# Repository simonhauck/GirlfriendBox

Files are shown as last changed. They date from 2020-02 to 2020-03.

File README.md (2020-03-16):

# GirlfriendBox_Present
This is a self-made present for your girlfriend or wife.

<p align="center">
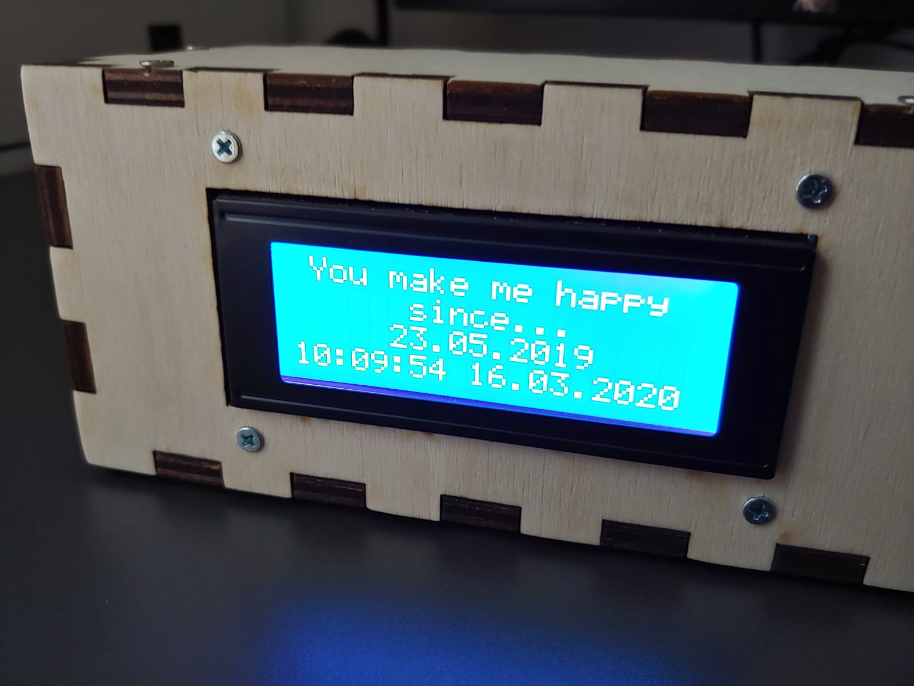
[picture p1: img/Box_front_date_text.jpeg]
  
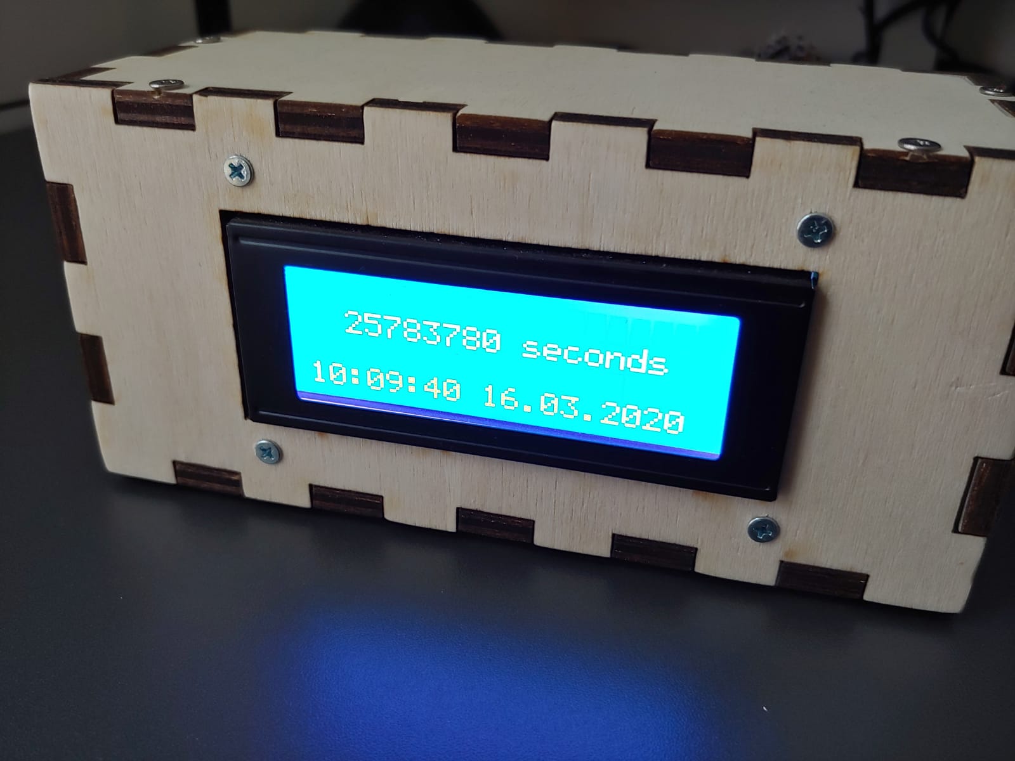
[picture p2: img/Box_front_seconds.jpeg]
  
</p>

It is a box, that counts how long you have been together or married in different units. It cycles through seconds, minutes, hours, days, months, years as well as a customizable text, that shows your “Date”. Additionally, it also displays the current date & time at the bottom of the display. 

The project idea is inspired by this [video](https://www.youtube.com/watch?v=PbRNsSK7r4M), but the code as well as the box were created by myself.

## What you need
- 1 Arduino, which is the "brain". I used the [Arduino Nano V3](https://store.arduino.cc/arduino-nano)
- 1 Real-Time-Clock Module, which keeps track of the time. I used the [DS3231](https://create.arduino.cc/projecthub/MisterBotBreak/how-to-use-a-real-time-clock-module-ds3231-bc90fe)
- 1 [I2C-LCD-Display](https://www.amazon.de/SainSmart-Character-Display-Mega2560-Duemilanove/dp/B007XRHBKA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) with 20 * 4 characters
- 3 [Buttons](https://www.amazon.de/Youmile-100er-Pack-Miniatur-Mikro-Taster-Tastschalter-Qualit%C3%A4tsschalter-Miniature-6-x-5-mm/dp/B07Q1BXV7T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) to set the current time
- 2 [Switches](https://www.digikey.de/product-detail/de/e-switch/EG1201A/EG1902-ND/101723?productid=101723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). The first is for power and the second for the backlicht of the display
- Optionally
  - 1 [Lipo-Battery](https://www.amazon.de/gp/product/B07XCRTXL9/ref=ppx_yo_dt_b_asin_title_o00_s00?ie=UTF8&psc=1), so that you don't require always a power cable. I used a model with 3.7V and 2600mAh
  - 1 [Lipo-Charging-Circuit](https://www.amazon.de/IZOKEE-TP4056-Lademodul-Lithium-Batterie-Charger/dp/B077XW1XBJ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), so that you can charge the battery 
  - 1 [Boost-Converter](https://www.amazon.de/gp/product/B07KW61VYM/ref=ppx_yo_dt_b_asin_title_o00_s00?ie=UTF8&psc=1), which increases the battery voltage to 7 Volts
  - Some soldering gear, if you want to make a nice PCB

## Build the circuit
<p align="center">
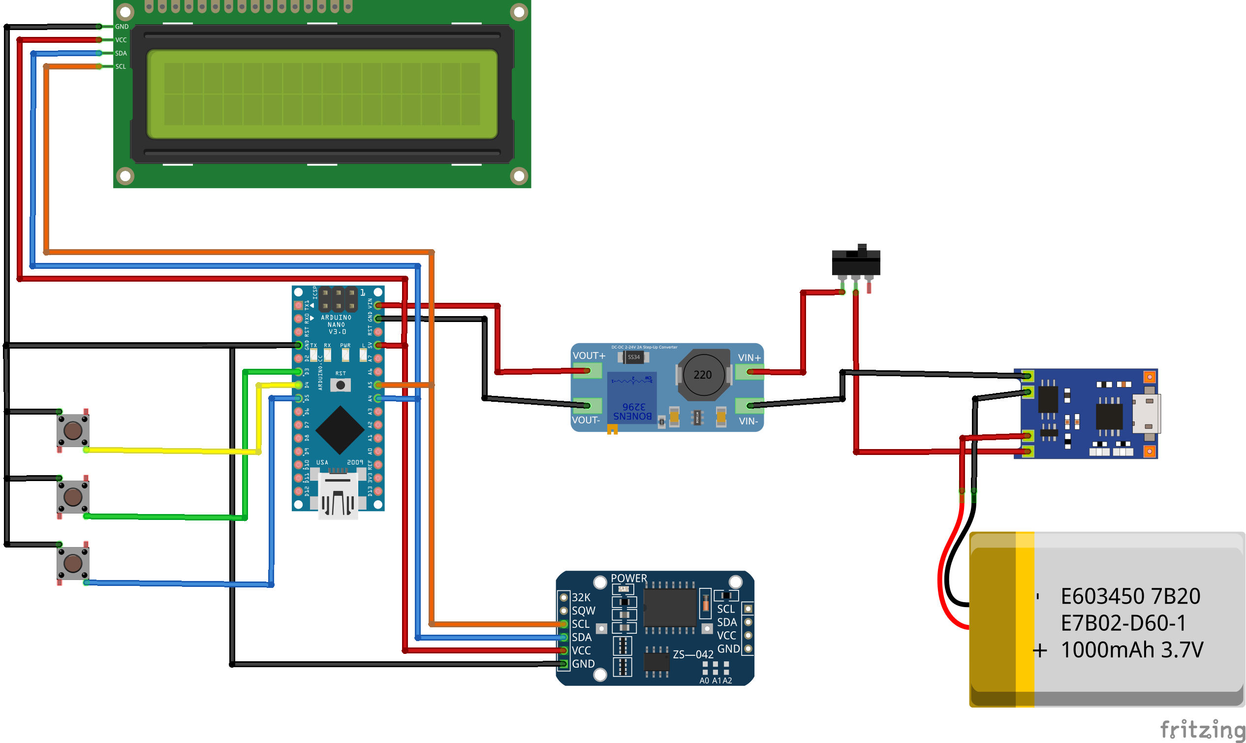
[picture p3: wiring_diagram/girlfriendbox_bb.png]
  
</p>
To build the circuit gather all the components and create the wiring according to the scheme provided in the “wiring_diagram” folder. Configure the boost-converter to output 7V. You can do this with a multimeter. Connect the probes to the + Pin  and - Pin of the boost-converter and measure the voltage. Rotate the potentiometer on the boost-convert until the multimeter shows 7V.

Note that this diagram contains only one switch for the power. The second is connected to the backlight pins of the I2C-Display. And now you are already done with the circuit :D yeahh 

Optionally you can create a small PCB for the wiring. This makes the assembly much cleaner. Additionally, I recommend using plugs between the components. This makes the assembly and/or maintenance if something breaks much more easy.

## Upload the code
After creating the circuit open the “girlfriendbox.ino” file with the Arduino IDE or something similar. Add the required libraries from the “lib” folder. In the Arduino IDE you can do this by clicking Sketch > Include Library > Add .ZIP Library. 
Now you should be able to upload the code to the Arduino and the program should run.

```C++
#define START_TIME_OF_COUNTER_TEXT "23.05.2019"
#define START_TIME_OF_COUNTER_UNIX_TIMESTAMP 1558569600
#define START_TIME_YEAR 2019
#define START_TIME_MONTH 5
#define START_TIME_DAY 23
```
The first one is the date shown on the display, the second is the same date as unix-timestamp, which is used to calculate the passed seconds, minutes, hours and days. You can use any online converter to get this timestamp. Note: You should add an offset for your timezone. So if you are in timezone +1 and your date is “23.05.2019 00:00” calculate the timestamp with “23.05.2019 01:00”. Last, add the date values for the day, month and year field. Personally I would prefer to calculate these values, but this would be a really big pain and soooo I ignored it... Anyways these are used to calculate the passed months and years, and of course, they only change on the monthly and yearly anniversary. 

Now you can change some more minor details, like the welcome text which will be shown initally and the units for seconds, month, ... , year if you prefer a different language. 

Upload the code to the arduino and set the current date and time. You can do this by pressing the config button (Pin 3). Increase and decrease the values with the buttons on Pin 4 and 5. If the value ist correct press the config button again.

## Build the case
Of course, you need a case for your box. I created one out of 6mm wood with the help of a laser cutter. If you have access to one of these, you can use the .dxf file in the folder “lasercutter_files”. If not, you have to manually cut/saw a box or you search for a company that will do this for you.

<p align="center">
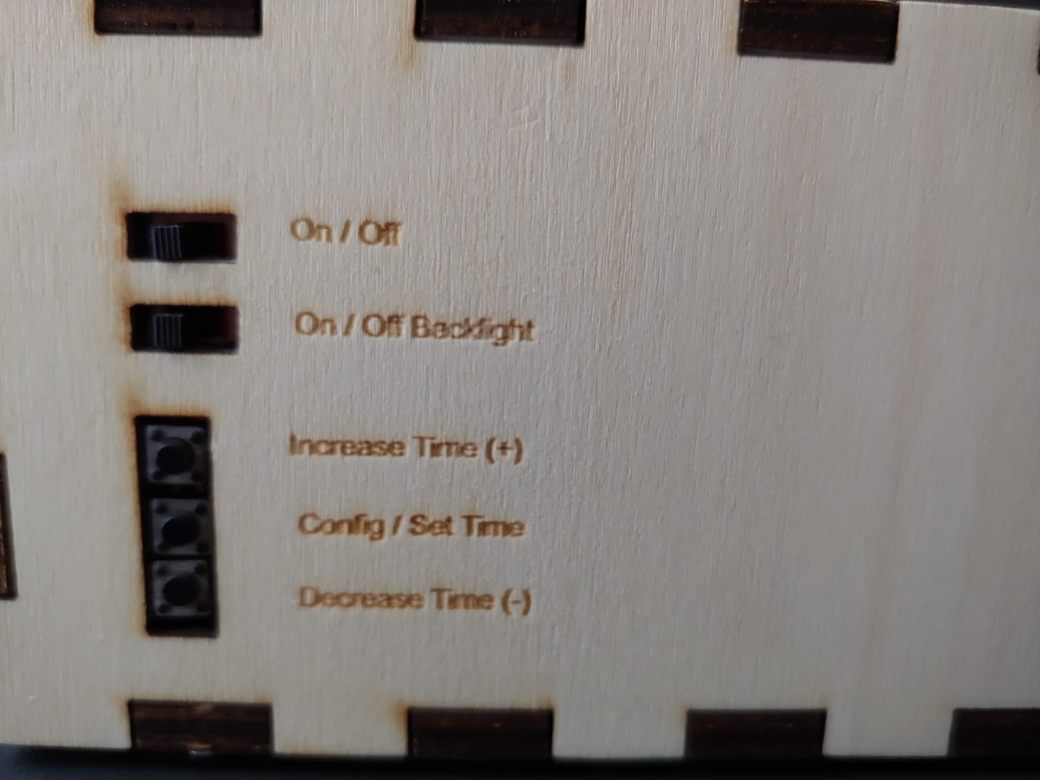
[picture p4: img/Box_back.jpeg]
  
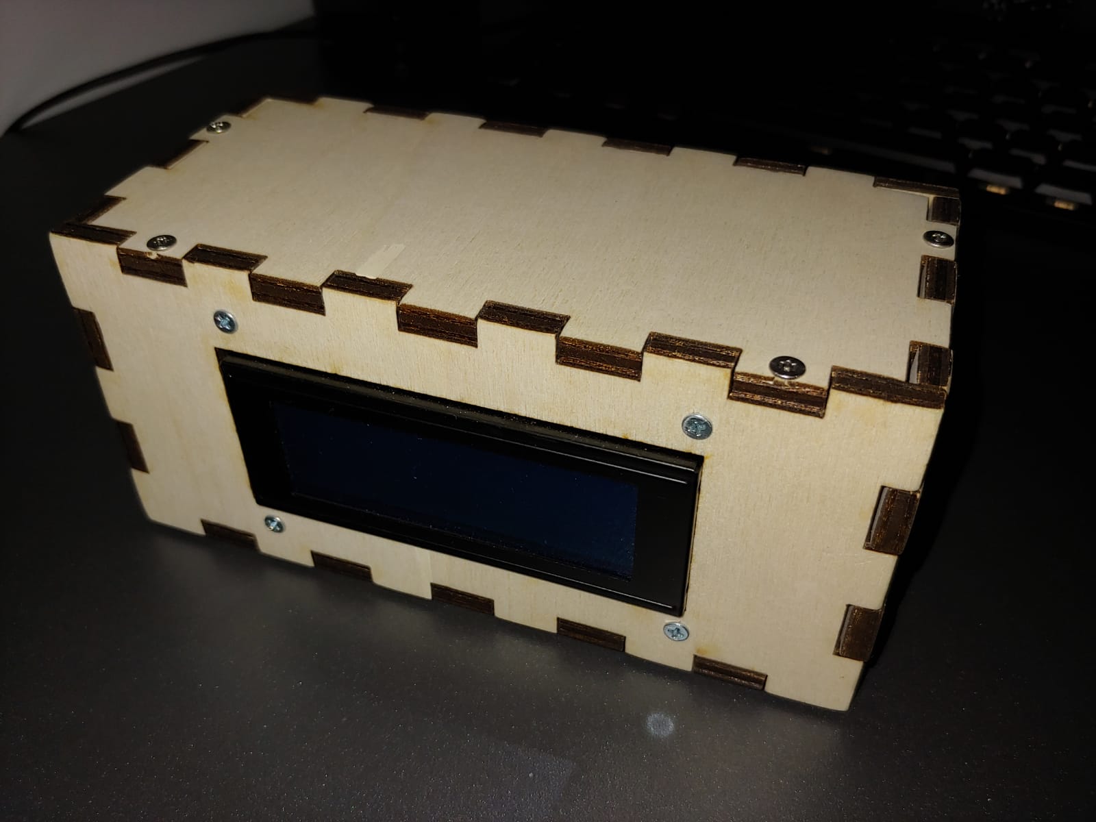
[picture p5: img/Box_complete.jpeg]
  
</p>
If you have your box, you must do some “post processing”. The .dxf file doest not include a hole for the charging-circuit, so you must create it manually. Screw the display in place and fixate the buttons and switches at the back of the case. I used a good amount of hot glue for that. To fixate the Lipo-battery I used some Velcro tape.

If all the components are securely mounted, close the box with some wood screws. This allows you to open it, if something is broken.
And now you are done and have a great present :D

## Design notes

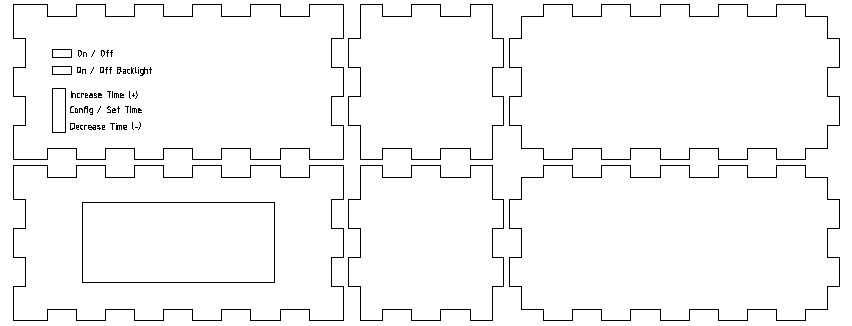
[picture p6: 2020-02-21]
lasercutter_files/box_display.png

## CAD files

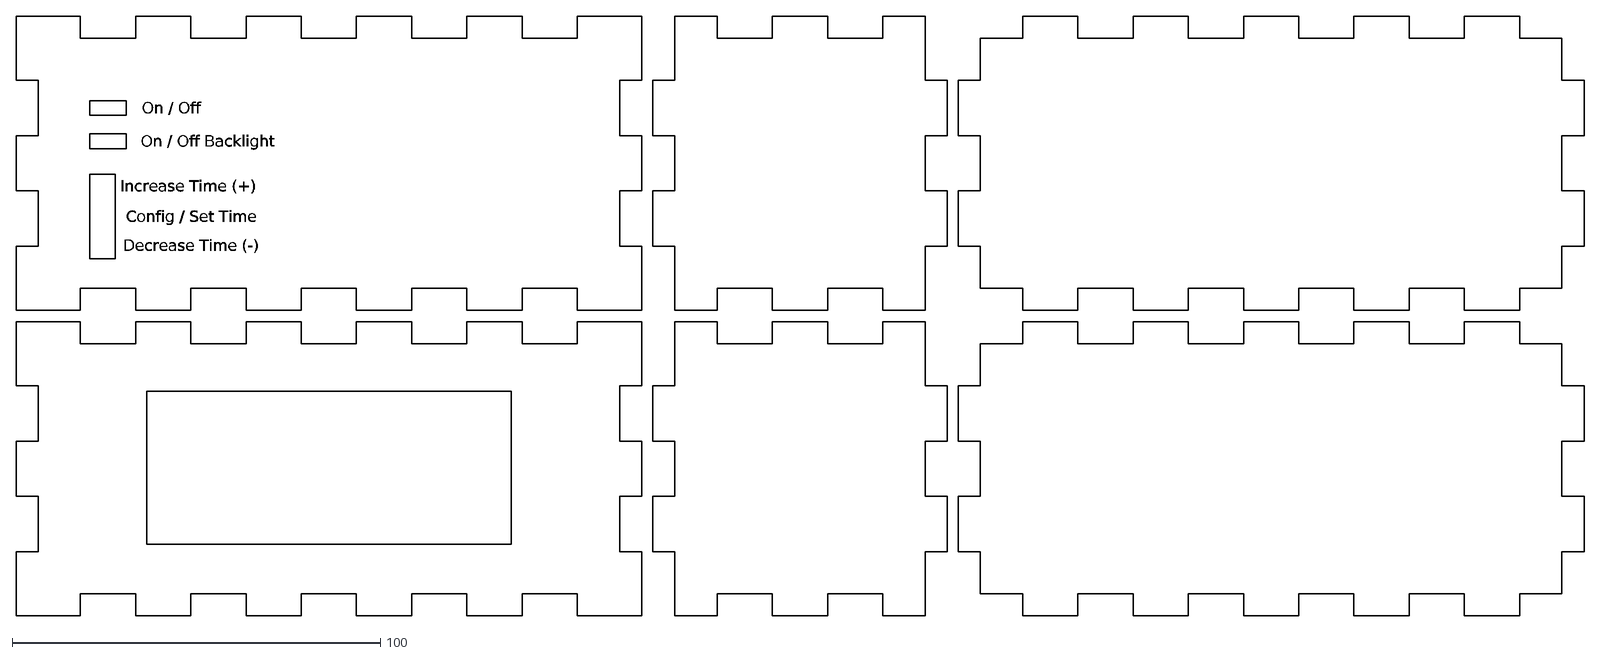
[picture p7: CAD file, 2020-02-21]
lasercutter_files/box_display.dxf
Increase Time (+)
Decrease Time (-)
Config / Set Time
On / Off
On / Off Backlight

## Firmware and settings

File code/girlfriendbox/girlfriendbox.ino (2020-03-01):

#include <Wire.h>
#include <LiquidCrystal_I2C.h>
#include "LowPower.h"
#include <DS3231.h>

#define PRINTLN(...)  {if(useSerial) {Serial.println(__VA_ARGS__);}};
#define PRINTLNF(...)  {if(useSerial) {Serial.println(F(__VA_ARGS__));}};
#define PRINT(...)  {if(useSerial) {Serial.print(__VA_ARGS__);}};
#define PRINTF(...)  {if(useSerial) {Serial.print(F(__VA_ARGS__));}};

#define LCD_WIDTH 20
#define LCD_HEIGHT 4

//Set start time as string to display, as array and timestamp, so that the calculation is easier
#define START_TIME_OF_COUNTER_TEXT "23.05.2019"
//TimeStamp, you can use your timezone, if you set the time also in the timezone
#define START_TIME_OF_COUNTER_UNIX_TIMESTAMP 1558569600
//Add year month and day as values... because i am to lazy to calculate those values from the timestamp ;)
#define START_TIME_YEAR 2019
#define START_TIME_MONTH 5
#define START_TIME_DAY 23


#define STATE_SHOW_DATE 0
#define STATE_CONFIG 1

//----------------------------------------------------------------------------------------------------------------------
// Displayed Text (Change for your language)
//----------------------------------------------------------------------------------------------------------------------

//Displayed text. Change it to match your use case
#define GREETING "Hello"

#define COUNTER_SUBJECT "You make me happy"
#define SINCE "since..."

#define THAT_IS "That's..."

#define OR "or..."

#define UNIT_SECONDS "seconds"
#define UNIT_MINUTES "minutes"
#define UNIT_HOURS "hours"
#define UNIT_DAYS "days"
#define UNIT_MONTH "months"
#define UNIT_YEAR "years"

//----------------------------------------------------------------------------------------------------------------------
// Fields & Variables
//----------------------------------------------------------------------------------------------------------------------

//Custom lcd Chars
byte lcdHeartChar[8] = {0x00, 0x0a, 0x1f, 0x1f, 0x0e, 0x04, 0x00};
byte lcdUpArrowChar[8] = {0x00, 0x00, 0x00, 0x00, 0x04, 0x0E, 0x1F, 0x1F};
byte lcdDownArrowChar[8] = {0x1F, 0x1F, 0x0E, 0x04, 0x00, 0x00, 0x00, 0x00};

//Pins for the buttons, configButton is an interrupt
const int configButtonPin = 3;
const int upButtonPin = 5;
const int downButtonPin = 4;
const unsigned int buttonDebounceTime = 500;

//Indicate if serial should be used
//If no usb device is connected, serial can not be opened
//Value is set automatically on startup
bool useSerial = true;

//LCD Display
LiquidCrystal_I2C lcd(0x27, 2, 1, 0, 4, 5, 6, 7, 3, POSITIVE);

//Clock objects
DS3231 rtcClock;
RTClib rtcLibClock;

//Button flag
volatile bool configButtonPressed = false;

//DateTime values
byte hour;
byte minute;
byte second;
byte day;
byte month;
int year;
long currentUnixTime;

// 0 - Show dates
// 1 - Configure time
byte state = STATE_SHOW_DATE;

//Time to show the same text in ms
//Time to show same text, 1 cycle is 1 sec
unsigned int textDisplayTimeCycles = 10;
unsigned long textDisplayCurrentCycle = 0;
byte displayedTextState = 0;
//Fields to cache display state to prevent flickering
byte lastDisplayedTextState = 0;

//Config state variables
byte configDateTimeState = 0;
int downButtonLastState = HIGH;
unsigned long lastTimeDownButtonPressed = 0;
int upButtonLastState = HIGH;
unsigned long lastTimeUpButtonPressed = 0;
unsigned long timeStampLastLcdDisplay = 0;
unsigned long lastTimeConfigButtonPressed = 0;
bool resetDisplay = false;


//----------------------------------------------------------------------------------------------------------------------
// Arduino functions
//----------------------------------------------------------------------------------------------------------------------

void setup() {
    // put your setup code here, to run once:

    //Set pins
    pinMode(configButtonPin, INPUT_PULLUP);
    pinMode(upButtonPin, INPUT_PULLUP);
    pinMode(downButtonPin, INPUT_PULLUP);

    initLCD();
    printGreeting();
    initSerial();

    //Initially reset lcd and display first text
    lcd.clear();

    //Attack interrupt
    lastTimeConfigButtonPressed = millis();
    attachInterrupt(digitalPinToInterrupt(configButtonPin), configButtonISR, FALLING);
    delay(100);
    state = STATE_SHOW_DATE;

}

void loop() {
    //Switch to config
    if (configButtonPressed) {
        if (debounceTimePassed(lastTimeConfigButtonPressed, buttonDebounceTime)) {
            lastTimeConfigButtonPressed = millis();

        } else {
            configButtonPressed = false;
        }
    }

    if (configButtonPressed && state != STATE_CONFIG) {
        configStateSetup();
    }

    switch (state) {
        case STATE_SHOW_DATE:
            dateState();
            break;
        case STATE_CONFIG:
            configState();
            break;
        default: PRINTLNF("WARNING: Default State in loop() used!");
            dateState();
    }

    PRINTLNF("----------------------------------");

    //Go to sleep / delay state = SHOW DATES
    if (state == STATE_SHOW_DATE) {
        PRINTLNF("Going to sleep");
        if (useSerial) Serial.flush();
        //delay(1000);
        LowPower.powerDown(SLEEP_1S, ADC_OFF, BOD_OFF);
        PRINTLNF("Wake up");
    }
}

/**
 * change the state to CONFIG and set the flag that the button was pressed and the display should be resetted
 */
void configButtonISR() {
    configButtonPressed = true;
}

//----------------------------------------------------------------------------------------------------------------------
// Functions
//----------------------------------------------------------------------------------------------------------------------

/**
 * initialize the serial module if usb is connected
 */
void initSerial() {
    Serial.begin(9600);
    lcd.setCursor(0, 3);

    //Wait for serial
    for (int i = 0; i < 20; i++) {
        lcd.print(".");
        delay(100);
    }

    //If Serial is not initialized, set flag to false
    if (!Serial) {
        useSerial = false;
    } else {
        useSerial = true;
        PRINTLN("Serial initialized.");
    }

}

/**
 * init the lcd display and clear all content
 */
void initLCD() {
    lcd.begin(LCD_WIDTH, LCD_HEIGHT);
    lcd.clear();

    //Create custom chars
    lcd.createChar(1, lcdHeartChar);
    lcd.createChar(2, lcdUpArrowChar);
    lcd.createChar(3, lcdDownArrowChar);
}

/**
 * print the greeting message to the display
 */
void printGreeting() {
    prepareCursorCenteredText(strlen(GREETING) + 4, 1);
    lcd.write(1);
    lcd.print(" ");
    lcd.print(GREETING);
    lcd.print(" ");
    lcd.write(1);
}

/**
 * handle the functions if the program is in the date state
 * Displays the passed time to the start date in different units
 */
void dateState() {
    PRINTF("DateState() Function State: ");
    PRINTLN(displayedTextState);

    getClockValues(hour, minute, second, day, month, year, currentUnixTime);
    printDateTime(hour, minute, second, day, month, year, currentUnixTime);

    //Reset if state change occurred
    if (lastDisplayedTextState != displayedTextState) {
        PRINTLNF("Resetting the Display");
        lcd.clear();
    }

    switch (displayedTextState) {
        case 0:
            printStartDateCounterLCD();
            break;
        case 1:
            printPassedTimeLCD(calculatePassedSeconds(), UNIT_SECONDS, strlen(UNIT_SECONDS), 1);
            break;
        case 2:
            printPassedTimeLCD(calculatePassedMinutes(), UNIT_MINUTES, strlen(UNIT_MINUTES), 1);
            break;
        case 3:
            printPassedTimeLCD(calculatePassedHours(), UNIT_HOURS, strlen(UNIT_HOURS), 1);
            break;
        case 4:
            printPassedTimeLCD(calculatePassedDays(), UNIT_DAYS, strlen(UNIT_DAYS), 1);
            break;
        case 5:
            printPassedTimeLCD(calculatePassedMonths(), UNIT_MONTH, strlen(UNIT_MONTH), 1);
            break;
        case 6:
            printPassedTimeLCD(calculatePassedYears(), UNIT_YEAR, strlen(UNIT_YEAR), 1);
            break;
        default:
            printStartDateCounterLCD();


    }

    printDateTimeLCD(hour, minute, second, day, month, year, 3, true);

    //Save last state before updating
    lastDisplayedTextState = displayedTextState;

    textDisplayCurrentCycle++;
    //Set new value if time has passed or and overflow happened
    if (textDisplayCurrentCycle >= textDisplayTimeCycles) {
        //Reset the state
        textDisplayCurrentCycle = 0;
        //7 Modes for default, seconds, minutes, hours, month, year
        displayedTextState = (displayedTextState + 1) % 7;
    }
}

/**
 * setup the config state, if it is nealy entered
 */
void configStateSetup() {
    PRINTLN("ConfigButton was pressed. Switch to config mode");
    configButtonPressed = false;
    upButtonLastState = HIGH;
    downButtonLastState = HIGH;
    state = STATE_CONFIG;
    configDateTimeState = 0;
    lcd.clear();
}

/**
 * Switch to the config state and set the time of the rtc clock
 */
void configState() {
    bool printFullDate = true;
    PRINTF("ConfigState() Function, State: ");
    PRINTLN(configDateTimeState);

    // The start position of the lcd
    byte lcdStartPosition = (LCD_WIDTH - (printFullDate ? 19 : 17)) / 2;

    //Check if a button was pressed
    bool downButtonPressed = false;
    bool upButtonPressed = false;
    if (detectButtonPressed(downButtonPin, downButtonLastState, lastTimeDownButtonPressed, buttonDebounceTime)) {
        downButtonPressed = true;
    } else if (detectButtonPressed(upButtonPin, upButtonLastState, lastTimeUpButtonPressed, buttonDebounceTime)) {
        upButtonPressed = true;
    }
    bool buttonPressed = downButtonPressed || upButtonPressed;

    //Reset display in new state
    if (configButtonPressed) {
        lcd.clear();
        configDateTimeState++;
    }

    // Write display if 1 second has passed or a button was pressed
    if (configButtonPressed || buttonPressed ||
        millis() >= timeStampLastLcdDisplay + 1000 ||
        millis() < timeStampLastLcdDisplay) {
        //Get current clock values
        getClockValues(hour, minute, second, day, month, year, currentUnixTime);
        resetDisplay = true;
        timeStampLastLcdDisplay = millis();

    }

    //Reset button
    configButtonPressed = false;


    switch (configDateTimeState) {
        case 0:
            //Set hour:
            if (resetDisplay) printArrowsLCD(2, lcdStartPosition, 1, true);
            if (resetDisplay) printArrowsLCD(2, lcdStartPosition, 3, false);
            if (downButtonPressed || upButtonPressed) {
                modifyHour(hour, upButtonPressed, downButtonPressed);
                rtcClock.setHour(hour);
            }
            PRINTLNF("Configure hour...");
            break;
        case 1:
            //Set minute:
            if (resetDisplay) printArrowsLCD(2, lcdStartPosition + 3, 1, true);
            if (resetDisplay) printArrowsLCD(2, lcdStartPosition + 3, 3, false);
            if (downButtonPressed || upButtonPressed) {
                modifyMinuteAndSecond(minute, upButtonPressed, downButtonPressed);
                rtcClock.setMinute(minute);
            }
            PRINTLNF("Configure minute...");
            break;
        case 2:
            //Set second:
            if (resetDisplay) printArrowsLCD(2, lcdStartPosition + 6, 1, true);
            if (resetDisplay) printArrowsLCD(2, lcdStartPosition + 6, 3, false);
            if (downButtonPressed || upButtonPressed) {
                modifyMinuteAndSecond(second, upButtonPressed, downButtonPressed);
                rtcClock.setSecond(second);
            }
            PRINTLNF("Configure second...");
            break;
        case 3:
            //Set day:
            if (resetDisplay) printArrowsLCD(2, lcdStartPosition + 9, 1, true);
            if (resetDisplay) printArrowsLCD(2, lcdStartPosition + 9, 3, false);
            if (downButtonPressed || upButtonPressed) {
                modifyDay(day, upButtonPressed, downButtonPressed);
                rtcClock.setDate(day);
            }
            PRINTLNF("Configure day...");
            break;
        case 4:
            //Set month:
            if (resetDisplay) printArrowsLCD(2, lcdStartPosition + 12, 1, true);
            if (resetDisplay) printArrowsLCD(2, lcdStartPosition + 12, 3, false);
            if (downButtonPressed || upButtonPressed) {
                modifyMonth(month, upButtonPressed, downButtonPressed);
                rtcClock.setMonth(month);
            }
            PRINTLNF("Configure month...");
            break;
        case 5:
            if (resetDisplay) printArrowsLCD((printFullDate ? 4 : 2), lcdStartPosition + 15, 1, true);
            if (resetDisplay) printArrowsLCD((printFullDate ? 4 : 2), lcdStartPosition + 15, 3, false);
            //Set year:
            if (downButtonPressed || upButtonPressed) {
                modifyYear(year, upButtonPressed, downButtonPressed);
                rtcClock.setYear(year - 2000);
            }
            PRINTLNF("Configure year...");
            break;
        default:
            state = STATE_SHOW_DATE;
            lcd.clear();
            //Restart counter on other state
            displayedTextState = 0;
            PRINTLNF("Config complete. Return to show date mode...");
            prepareCursorCenteredText(16, 1);
            lcd.print("Config complete!");
            delay(1000);
            lcd.clear();
            return;
    }

    //Write time and day after value was potentially updated
    if (resetDisplay) {
        prepareCursorCenteredText(15, 0);
        lcd.print("Set Date & Time");
        printDateTimeLCD(hour, minute, second, day, month, year, 2, printFullDate);
    }

    delay(100);
}

/**
 * set the cursor so, that the text width the given length will be centered
 * @param textLength the length of the text
 * @param row the row to which the cursor should be set
 */
void prepareCursorCenteredText(byte textLength, byte row) {
    if (textLength >= LCD_WIDTH) {
        lcd.setCursor(0, row);
    } else {
        byte position = (LCD_WIDTH - textLength) / 2;
        lcd.setCursor(position, row);
    }
}

/**
 * print the values of the date to the serial monitor
 * @param hour value that should be displayed
 * @param minute value that should be displayed
 * @param second value that should be displayed
 * @param day value that should be displayed
 * @param month value that should be displayed
 * @param year value that should be displayed
 * @param unixTimeStamp value that should be displayed
 */
void printDateTime(byte hour, byte minute, byte second, byte day, byte month, int year, long unixTimeStamp) {
    PRINT(hour);
    PRINT(":");
    PRINT(minute);
    PRINT(":");
    PRINT(second);
    PRINT(" ");
    PRINT(day);
    PRINT(".");
    PRINT(month);
    PRINT(".");
    PRINT(year);
    PRINT(", unixTimeStamp: ");
    PRINTLN(unixTimeStamp);
}

/**
 * print the date centered to the display in the given row
 * @param hour the given hour, should be in 24h mode
 * @param minute the minute that should be displayed
 * @param second the second that should be displayed
 * @param day the day that should be displayed
 * @param month the month that should be displayed
 * @param year the year that should be displayed
 * @param row in which the text should be displayed
 * @param printFullYear True if the year should be printed. Eg. true = 2019 false = 19
 * @param century20th True if the year is 20** or false if the year is 19**
 */
void printDateTimeLCD(byte hour, byte minute, byte second, byte day, byte month, int year, byte row,
                      bool printFullYear) {
    //Depending on the year the text has 19 or 17 chars
    prepareCursorCenteredText((printFullYear ? 19 : 17), row);

    if (hour < 10) {
        lcd.print(" ");
    }
    lcd.print(hour);

    lcd.print(":");
    if (minute < 10) {
        lcd.print("0");
    }
    lcd.print(minute);

    lcd.print(":");
    if (second < 10) {
        lcd.print("0");
    }
    lcd.print(second);

    lcd.print(" ");

    if (day < 10) {
        lcd.print("0");
    }
    lcd.print(day);

    lcd.print(".");
    if (month < 10) {
        lcd.print("0");
    }
    lcd.print(month);

    lcd.print(".");
    lcd.print((printFullYear ? year : year - 2000));
}

/**
 * print the counter start date to the lcd display with the defined reason
 */
void printStartDateCounterLCD() {
    prepareCursorCenteredText(strlen(COUNTER_SUBJECT), 0);
    lcd.print(COUNTER_SUBJECT);
    prepareCursorCenteredText(strlen(SINCE), 1);
    lcd.print(SINCE);
    prepareCursorCenteredText(strlen(START_TIME_OF_COUNTER_TEXT), 2);
    lcd.print(START_TIME_OF_COUNTER_TEXT);
}

/**
 * print the given time and unit to the display in the given row
 * @param value the time value that should be displayed
 * @param unit the unit of the time that should be displayed
 * @param textLengthUnit the length of the unit string
 * @param row the row in which the characters should be displayed
 */
void printPassedTimeLCD(unsigned long value, char unit[], byte textLengthUnit, byte row) {
    byte totalLength = 1 + getLengthOfNumber(value) + textLengthUnit;
    prepareCursorCenteredText(totalLength, row);
    lcd.print(value);
    lcd.print(" ");
    lcd.print(unit);
}

/**
 * get the length of the given number
 * @param value the number from which the length will be returned
 * @return the length of the number
 */
unsigned int getLengthOfNumber(unsigned long value) {
    unsigned int counter = 1;
    unsigned long divisionValue = 1;

    while (true) {
        divisionValue *= 10;
        unsigned long divisionResult = value / divisionValue;
        if (divisionResult >= 1) {
            counter++;
        } else {
            return counter;
        }
    }
}

/**
 * set the time of the rtc clock
 * @param hour the current hour value
 * @param minute the current minute value
 * @param second the current second value
 * @param day the current day value
 * @param month the current month value
 * @param year the current year value
 * @param clockMode the clock mode. EG true = 24h false = 12h clock
 */
void setClockTime(byte hour, byte minute, byte second, byte day, byte month, int year, bool clockMode) {
    rtcClock.setClockMode(false);
    //Needs 1 byte as value -> Lib adds 2000 + offset
    byte tmpYear = (year - 2000);
    rtcClock.setYear(tmpYear);
    rtcClock.setMonth(month);
    rtcClock.setDate(day);
    rtcClock.setHour(hour);
    rtcClock.setMinute(minute);
    rtcClock.setSecond(second);
}

/**
 * get the values from the rtc and write the values in the given parameters
 * @param hour write result hour value of the rtc into the parameter
 * @param minute write result minute value of the rtc into the parameter
 * @param second write result second value of the rtc into the parameter
 * @param day write result day value of the rtc into the parameter
 * @param month write result month value of the rtc into the parameter
 * @param year write result hour value from the rtc in parameter -> can only display values 20**
 * @param currentUnixTime write result unix timestamp value (in sec) of the rtc into the parameter
 */
void getClockValues(byte &hour, byte &minute, byte &second, byte &day, byte &month, int &year, long &currentUnixTime) {
    DateTime now = rtcLibClock.now();
    hour = now.hour();
    minute = now.minute();
    second = now.second();
    day = now.day();
    month = now.month();
    year = now.year();
    currentUnixTime = now.unixtime();
}

/**
 * print the arrows on the lcd at the given position
 * @param amount the amount of arrows that should be printed
 * @param xPos the x position on the lcd of the first char
 * @param yPos the y position on the lcd of the first char
 * @param up true if the arrows should face up
 */
void printArrowsLCD(byte amount, byte xPos, byte yPos, bool up) {
    lcd.setCursor(xPos, yPos);
    for (int i = 0; i < amount; i++) {
        lcd.write((up) ? 2 : 3);
    }
}

/**
 * return true if the debounce time has passed of a button
 * @param lastTimeButtonPressed last time the button was pressed
 * @param debounceTime the time it should wait
 * @return true if the time has passed
 */
bool debounceTimePassed(unsigned long lastTimeButtonPressed, unsigned int debounceTime) {
    long time = millis();
    PRINTLN(time < lastTimeButtonPressed || time > lastTimeButtonPressed + debounceTime);
    return time < lastTimeButtonPressed || time > lastTimeButtonPressed + debounceTime;
}

/**
 * detect if the given button at the given pin was pressed
 * @param buttonPin the pin of the button
 * @param lastState the last state of the button
 */
bool detectButtonPressed(byte buttonPin, int &lastState, unsigned long &lastTimeButtonPressed,
                         unsigned int debounceTime) {
    int state = digitalRead(buttonPin);
    if (state == LOW && lastState == HIGH && debounceTimePassed(lastTimeButtonPressed, debounceTime)) {
        lastState = state;
        lastTimeButtonPressed = millis();

        return true;
    }

    //Reset button
    if (state == HIGH && lastState == LOW) {
        lastState = HIGH;
    }
    return false;
}

/**
 * increase or decrease the hour value by one
 * @param val current hour value
 * @param increase increase the value
 * @param decrease  decrease the value
 */
void modifyHour(byte &val, bool increase, bool decrease) {
    if (increase) {
        val = (val + 1) % 24;
    }
    if (decrease) {
        //With byte -1 is 255
        if (val == 0) val = 23;
        else val--;
    }
}

/**
 * increase or decrease the second or minute value by one
 * @param val current second/minute value
 * @param increase increase the value
 * @param decrease  decrease the value
 */
void modifyMinuteAndSecond(byte &val, bool increase, bool decrease) {

    if (increase) {
        val = (val + 1) % 60;
    }
    if (decrease) {
        //With byte -1 is 255
        if (val == 0) val = 59;
        else val--;
    }
}
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

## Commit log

2020-01-14 initial arduino sketch
2020-01-14 initial led test
2020-01-19 bug fixes and code cleanup
    [girlfriendbox.ino]
2020-01-19 add functions to get and set the rtc value, display correct time values on lcd
    [girlfriendbox.ino]
2020-02-16 add wiring diagram
    [girlfriendbox.fzz]
2020-02-16 fix bug of timer stop with sleep
    [girlfriendbox.ino]
2020-02-16 update wiring diagram
    [girlfriendbox.fzz]
2020-02-21 add laser cutter box
    [box_display.dxf]
2020-02-21 fix serial bug, add sleep log statements, add initial state delay
    [girlfriendbox.ino]
2020-02-21 detect bug: if serial is not initialized, time cant be updated or loop does not run?
    [girlfriendbox.ino]
2020-03-01 update month and year calculation increase button debounce time
